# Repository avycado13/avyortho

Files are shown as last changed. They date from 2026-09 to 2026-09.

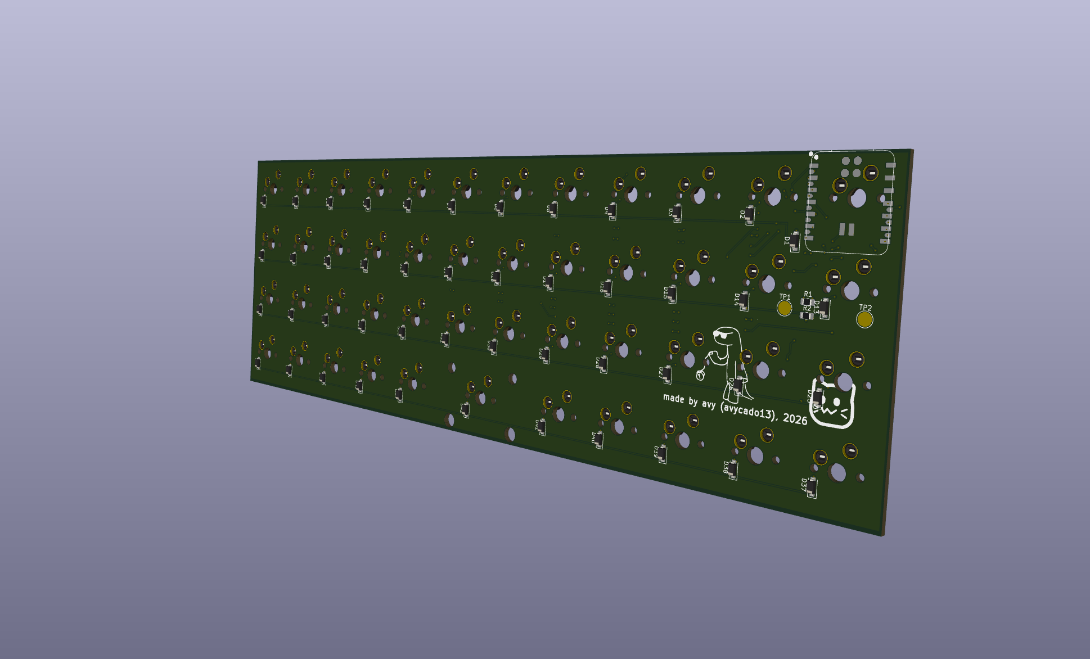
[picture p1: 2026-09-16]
images/avyortho-3b.png

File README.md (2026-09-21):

# AvyOrtho
A basic 40% ortholinear keyboard that uses vim keys for arrows

PCB

I wanted to make a nice keyboard and I wanted one that could be small and easy to carry in my backpack. I decided on an ortholinear because I figured they would be a lot easier to build and route because the keys aren't spaced weirdly. I decided to use ZMK for my firmware because there are nice tools to let you export your JSON from keyboard layout editor and turn it into firmware for ZMK. I used a Seeed Studios XIAO nRF52840 Plus for the microcontroller because it had enough GPIO pins and because it could do batteries without external devices needed

 I chose to go with a minimal 4x12 setup so I could fit it in my bag and to make it cooler. I will probably do keys like function keys with a layer and a modifier key for other functionality. In my next keyboard, I might consider adding RGB lights with something like a sk6812-mini. I will probably mainly use this keyboard on the go and then build a bigger keyboard as my home keyboard.

## Bill of Materials

Components on the PCB (full BOM in [`production/bom.csv`](production/bom.csv)):

| Part | Designators | Qty | Value / Part # | Footprint | Source |
|---|---|-----|---|---|---|
| Diodes | D1-D48 | 47 | 1N4148W (SMD) | D_SOD-123 | [LCSC C241939](https://lcsc.com/product-detail/C241939.html) |
| Resistor | R1 | 1 | 806kΩ | 0805 | CRCW0805806KFKEA |
| Resistor | R2 | 1 | 2MΩ | 0805 | CRCW08052M00FKED |
| MX hotswap sockets | SW1-SW48 | 47 | CPG151101S11-16 (Kailh) | SW_MX_HS | [Adafruit 4958](https://www.adafruit.com/product/4958) |
| MCU | U3 | 1 | Seeed XIAO nRF52840 Plus | XIAO-nRF52840-Plus | [Mouser 713-102010672](https://www.mouser.com/ProductDetail/713-102010672) |

Also these parts for the actual build
- 47x MX switches (any 1u, hot swappable)
- 47x keycaps (1u)
- Case + plate (see [`cad/`](cad/))

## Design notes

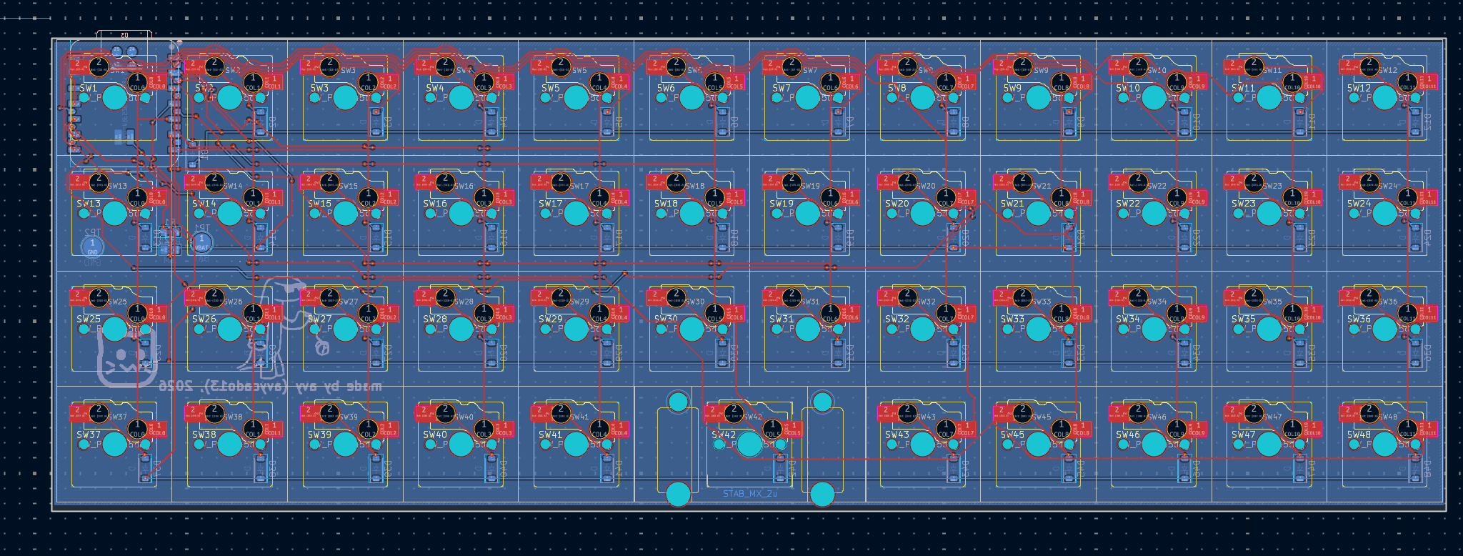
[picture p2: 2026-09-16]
images/avyortho-3a.png

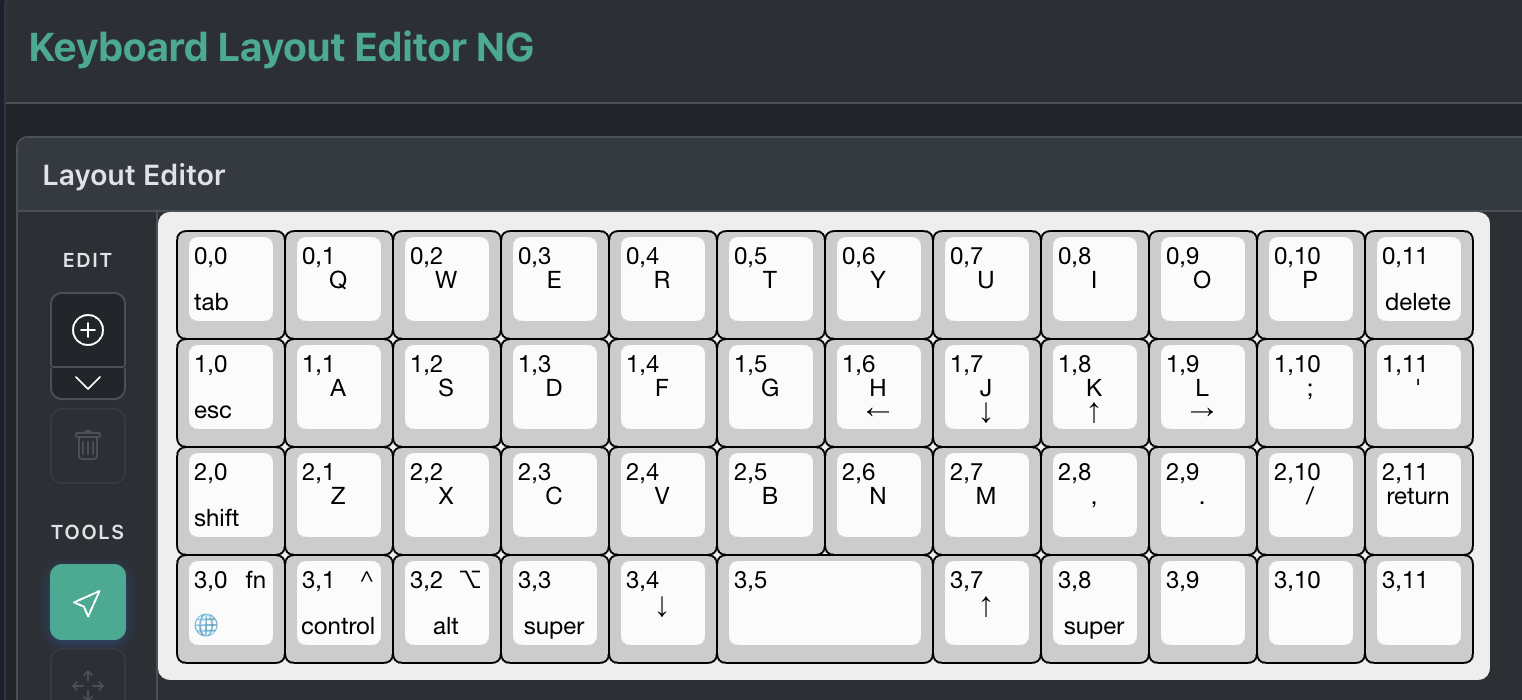
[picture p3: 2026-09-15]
images/avyortho-1a.png

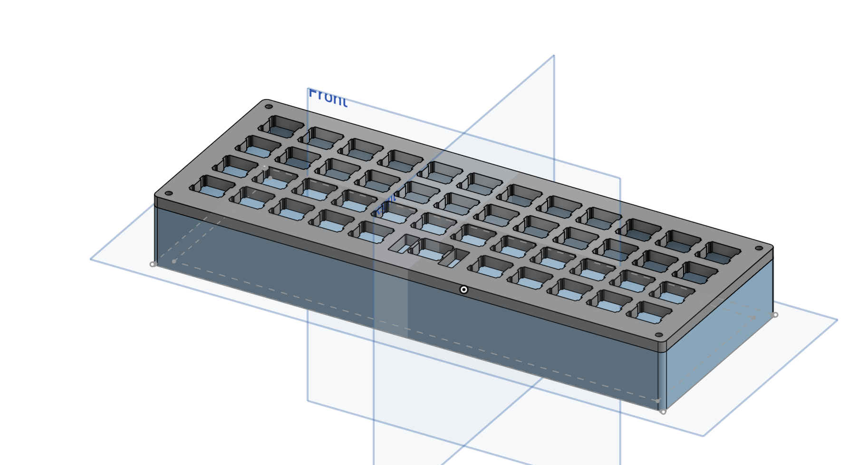
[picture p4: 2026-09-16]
images/avyortho-4.png

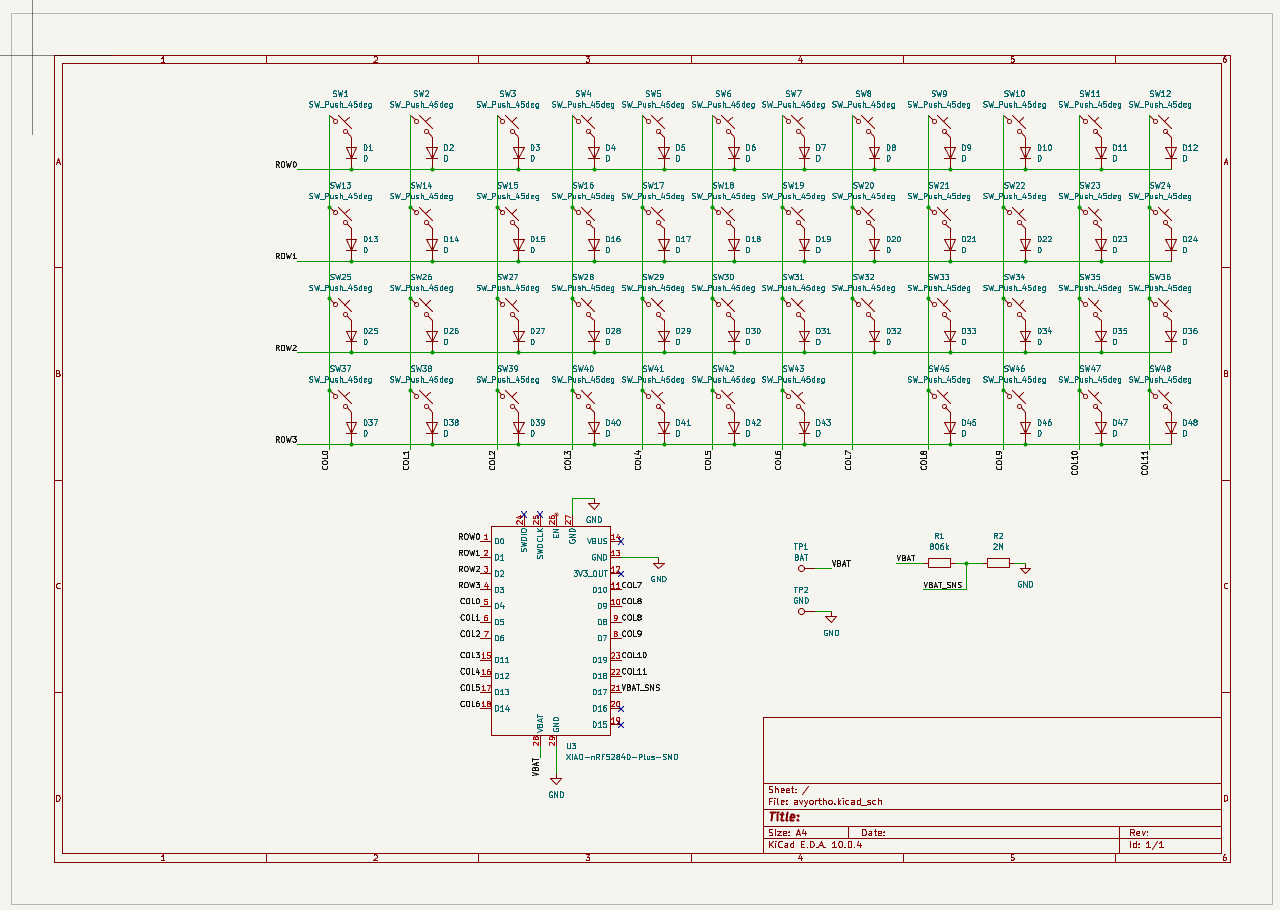
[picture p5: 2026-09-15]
images/avyortho-1b.png

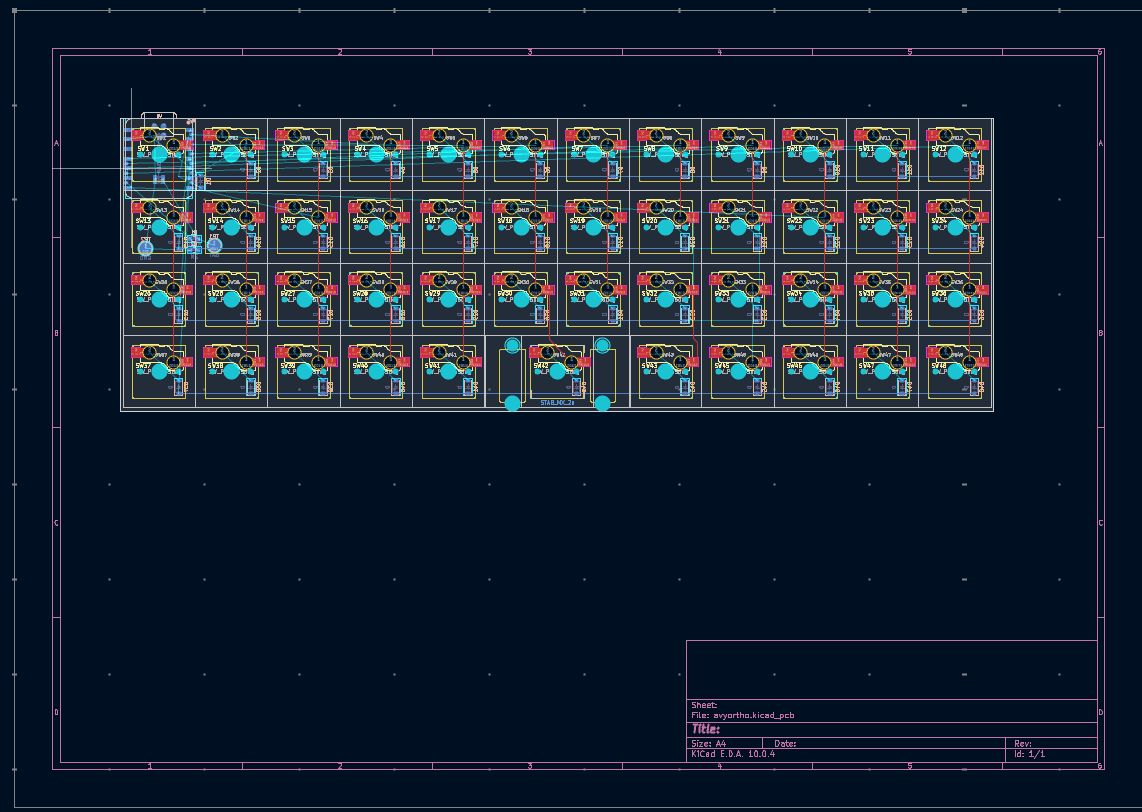
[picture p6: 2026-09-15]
images/avyortho-2.png

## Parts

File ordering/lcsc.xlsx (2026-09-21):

Designator | Footprint | Quantity | Value | LCSC Part # | Original Part | Original Manufacturer | Matched Part Number | Part Match | Description | Quantity | Selected Offers | Selected Distributor | Selected Distributor SKU | Selected Offers (Distributor Link) | Stock | Unit Price, $ | Total Quantity | Total Price
D1, D2, D3, D4, D5, D6, D7, D8, D9, D10, D11, D12, D13, D14, D15, D16, D17, D18, D19, D20, D21, D22, D23, D24, D25, D26, D27, D28, D29, D30, D31, D32, D33, D34, D35, D36, D37, D38, D39, D40, D41, D42, D43, D45, D46, D47, D48 | D_SOD-123 | 47 | D | 1N4148W | 1N4148W |  | 1N4148W-E3-08 | Selected | Rectifier Diode, 1 Phase, 1 Element, 0.15A, 100V V(RRM), Silicon, DO-35 | 47 | LCSC C241939 (https://octopart.com/opatz8j6/a1) | LCSC | C241939 (https://octopart.com/opatz8j6/a1) | https://octopart.com/opatz8j6/a1 | 41470 | 0.037 | 50 | 1.85

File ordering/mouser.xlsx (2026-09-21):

Designator | Footprint | Quantity | Value | LCSC Part # | Original Part | Original Manufacturer | Matched Part Number | Part Match | Description | Quantity | Selected Offers | Selected Distributor | Selected Distributor SKU | Selected Offers (Distributor Link) | Stock | Unit Price, $ | Total Quantity | Total Price
R1 | 0805 | 1 | 806k | CRCW0805806KFKEA | CRCW0805806KFKEA |  | CRCW0805806KFKEA | Exact | Res Thick Film 0805 806K Ohm 1% 0.125W(1/8W) ±100ppm/C Pad SMD T/R Automotive AEC-Q200 | 1 | Mouser 71-CRCW0805-806K-E3 (https://octopart.com/opatz8j6/a1) | Mouser | 71-CRCW0805-806K-E3 (https://octopart.com/opatz8j6/a1) | https://octopart.com/opatz8j6/a1 | 23708 | 0.1 | 1 | 0.1
R2 | 0805 | 1 | 2M | CRCW08052M00FKED | CRCW08052M00FKED |  | CPF0805B2M0E | Selected | Fixed Resistor, Thin Film, 0.1W, 2000000ohm, 0.1% +/-Tol, 25ppm/Cel, Surface Mount, 0805 | 1 | Mouser 279-CPF0805B2M0E (https://octopart.com/opatz8j6/a1) | Mouser | 279-CPF0805B2M0E (https://octopart.com/opatz8j6/a1) | https://octopart.com/opatz8j6/a1 | 9866 | 0.25 | 1 | 0.25
SW1, SW2, SW3, SW4, SW5, SW6, SW7, SW8, SW9, SW10, SW11, SW12, SW13, SW14, SW15, SW16, SW17, SW18, SW19, SW20, SW21, SW22, SW23, SW24, SW25, SW26, SW27, SW28, SW29, SW30, SW31, SW32, SW33, SW34, SW35, SW36, SW37, SW38, SW39, SW40, SW41, SW42, SW43, SW45, SW46, SW47, SW48 | SW_MX_HS_CPG151101S11_1u | 3 | SW_Push_45deg | CPG151101S11-16 | CPG151101S11-16 |  | 4958 | Selected | Kailh Switch Sockets For Mx-Compatible Mechanical Keys - 20 Pack |Adafruit 4958 | 3 | Mouser 485-4958 (https://octopart.com/opatz8j6/a1) | Mouser | 485-4958 (https://octopart.com/opatz8j6/a1) | https://octopart.com/opatz8j6/a1 | 48 | 4.95 | 3 | 14.85
U3 | XIAO-nRF52840-Plus-SMD | 1 | XIAO-nRF52840-Plus-SMD | 102010672 | 102010672 |  | 102010672 | Exact | Xiao NRF52840 Plus | 1 | Mouser 713-102010672 (https://octopart.com/opatz8j6/a1) | Mouser | 713-102010672 (https://octopart.com/opatz8j6/a1) | https://octopart.com/opatz8j6/a1 | 176 | 10.4 | 1 | 10.4

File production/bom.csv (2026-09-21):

Designator | Footprint | Quantity | Value | LCSC Part #
D1, D10, D11, D12, D13, D14, D15, D16, D17, D18, D19, D2, D20, D21, D22, D23, D24, D25, D26, D27, D28, D29, D3, D30, D31, D32, D33, D34, D35, D36, D37, D38, D39, D4, D40, D41, D42, D43, D45, D46, D47, D48, D5, D6, D7, D8, D9 | D_SOD-123 | 47 | D | 1N4148W
R1 | 0805 | 1 | 806k | CRCW0805806KFKEA
R2 | 0805 | 1 | 2M | CRCW08052M00FKED
SW1, SW10, SW11, SW12, SW13, SW14, SW15, SW16, SW17, SW18, SW19, SW2, SW20, SW21, SW22, SW23, SW24, SW25, SW26, SW27, SW28, SW29, SW3, SW30, SW31, SW32, SW33, SW34, SW35, SW36, SW37, SW38, SW39, SW4, SW40, SW41, SW42, SW43, SW45, SW46, SW47, SW48, SW5, SW6, SW7, SW8, SW9 | SW_MX_HS_CPG151101S11_1u | 47 | SW_Push_45deg | CPG151101S11-16
U3 | XIAO-nRF52840-Plus-SMD | 1 | XIAO-nRF52840-Plus-SMD | 102010672

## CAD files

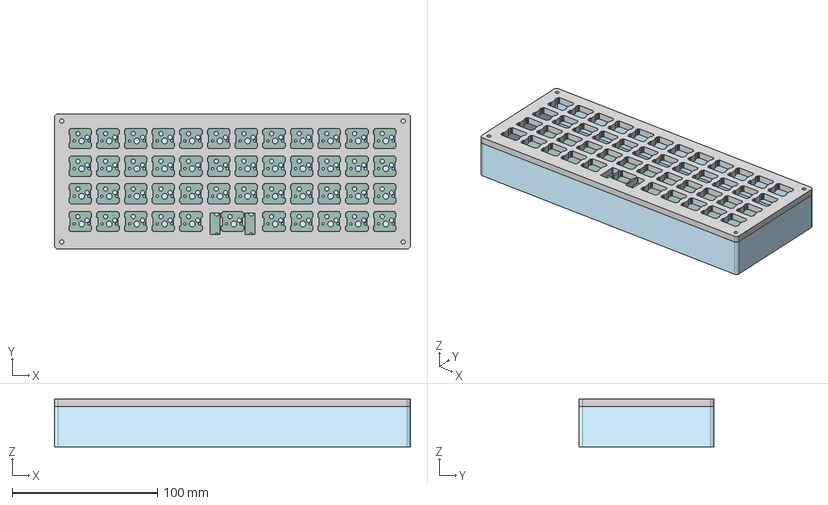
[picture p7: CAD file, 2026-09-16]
cad/full-assembly.step
245.2 x 93.1 x 33.0 mm
avyortho_PCB

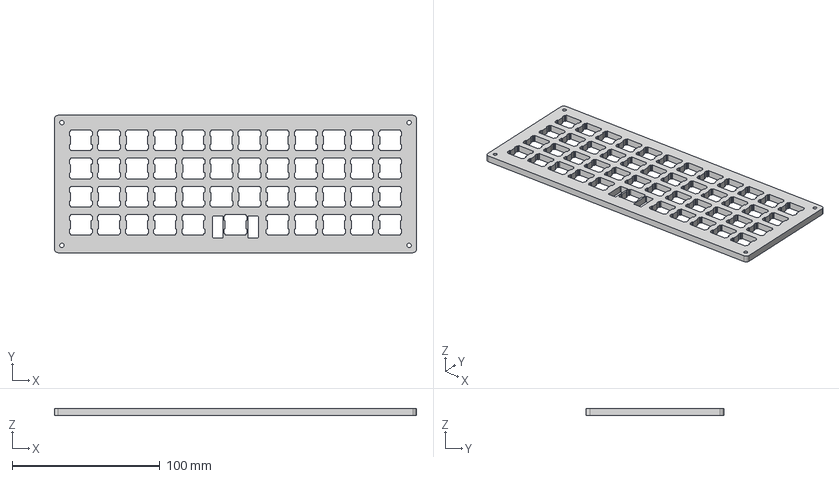
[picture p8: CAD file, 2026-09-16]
cad/plate.step
245.2 x 93.1 x 5.00 mm

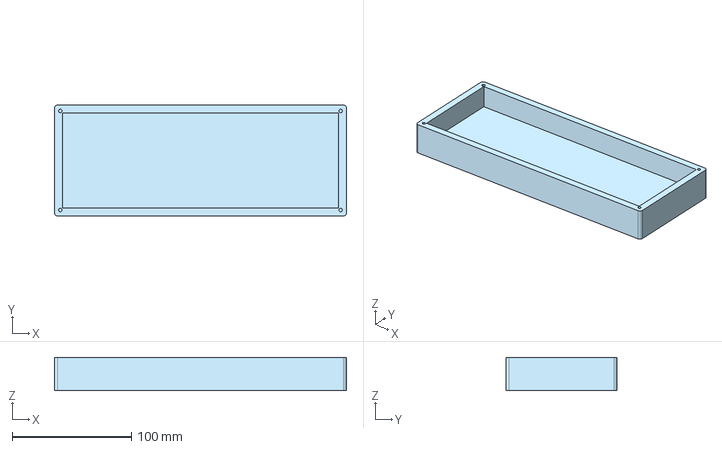
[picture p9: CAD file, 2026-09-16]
cad/body.step
245.2 x 93.1 x 28.0 mm

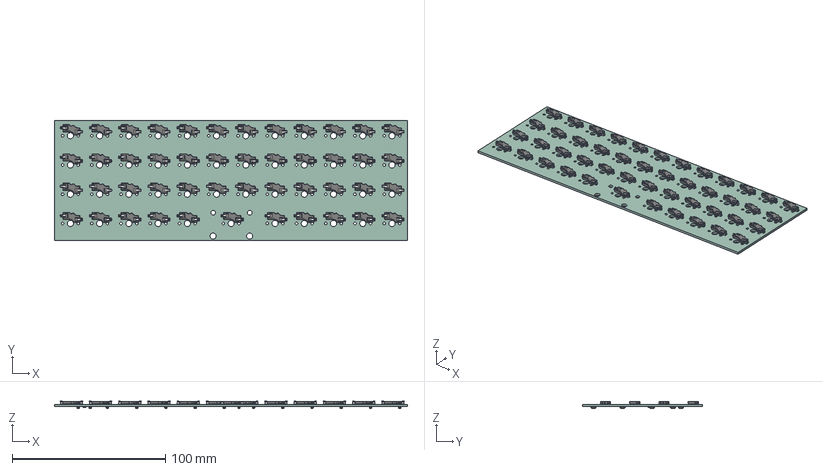
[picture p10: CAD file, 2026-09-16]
cad/pcb.step
230.0 x 78.0 x 4.74 mm
HS_gat_mx v8 x 47
D_SOD-123 x 47
R_0805_2012Metric x 2
avyortho_PCB

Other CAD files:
cad/body.3mf

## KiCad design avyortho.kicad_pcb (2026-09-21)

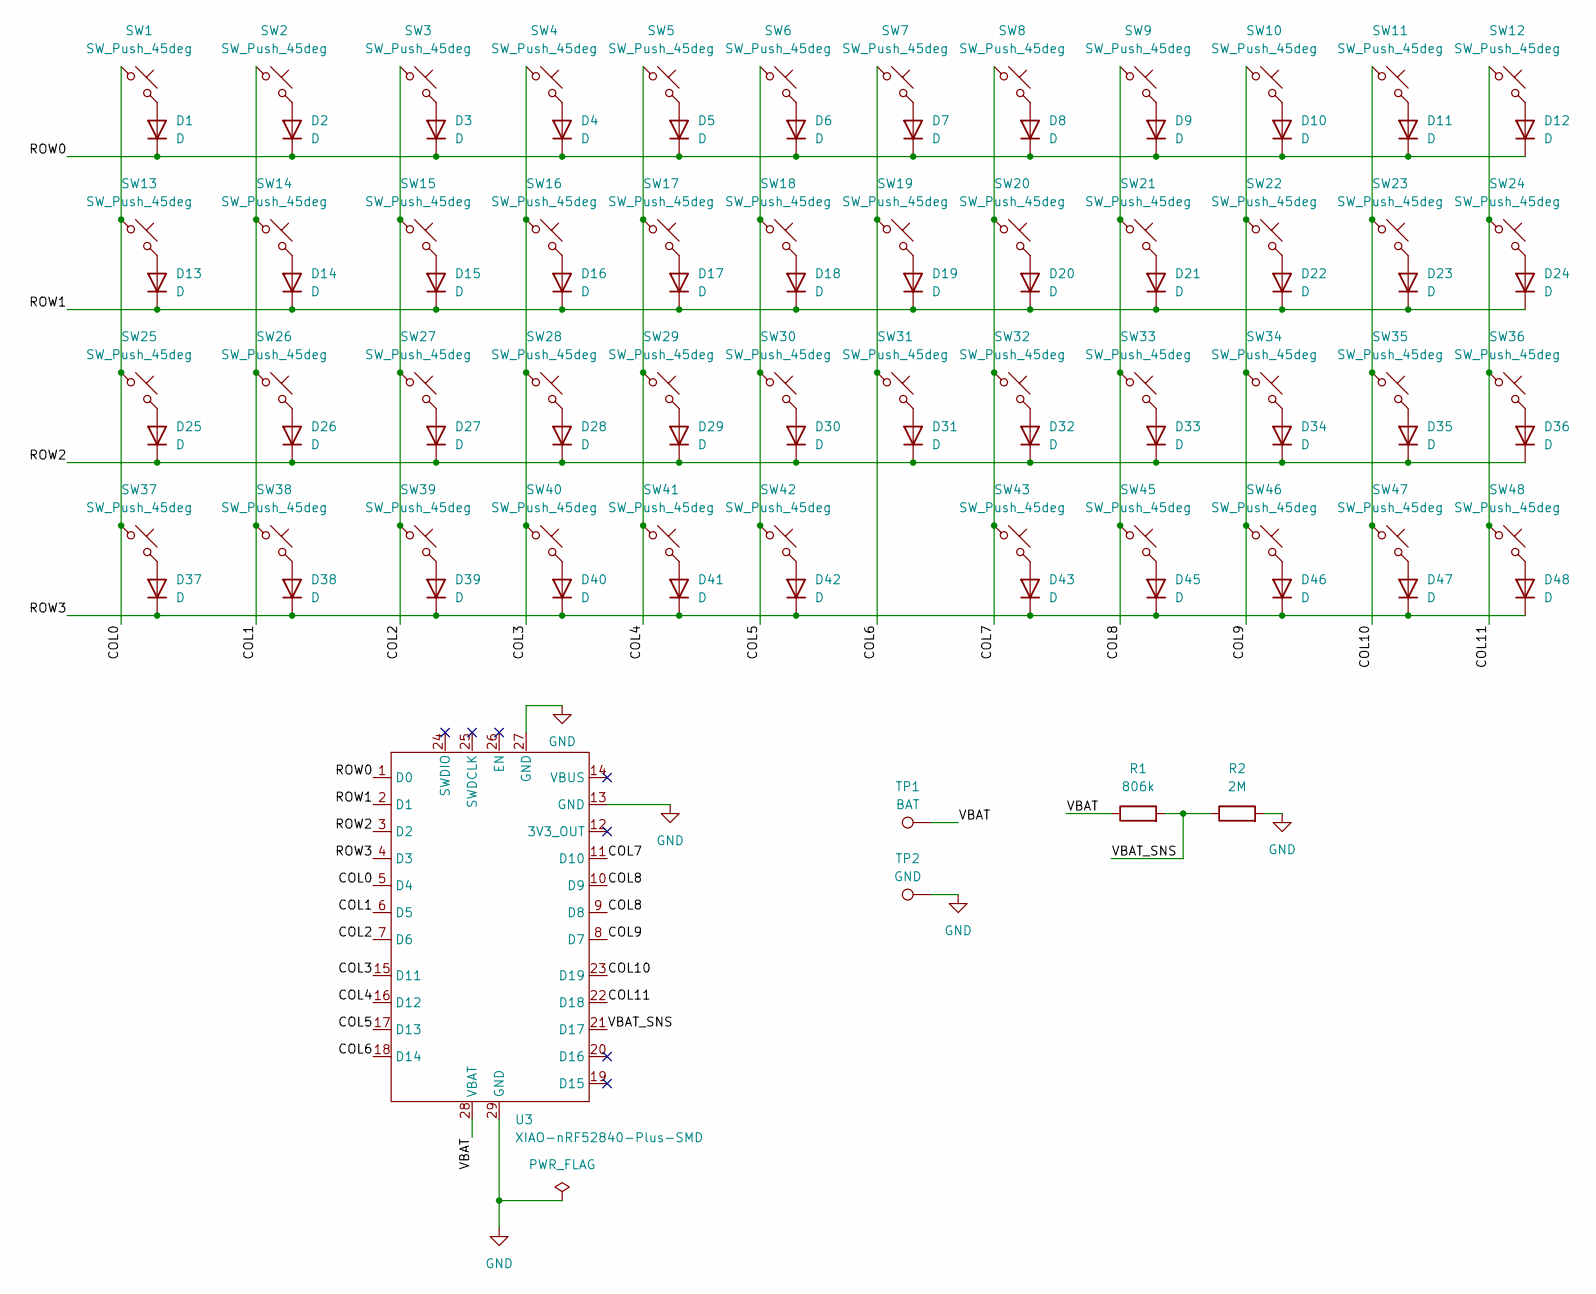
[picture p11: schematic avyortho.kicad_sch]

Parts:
D1, D2, D3, D4, D5, D6, D7, D8, D9, D10, D11, D12, D13, D14, D15, D16, D17, D18, D19, D20, D21, D22, D23, D24, D25, D26, D27, D28, D29, D30, D31, D32, D33, D34, D35, D36, D37, D38, D39, D40, D41, D42, D43, D45, D46, D47, D48: D; D_SOD-123; MPN 1N4148W
R1: 806k; R_0805_2012Metric_Pad1.20x1.40mm_HandSolder; MPN CRCW0805806KFKEA
R2: 2M; R_0805_2012Metric_Pad1.20x1.40mm_HandSolder; MPN CRCW08052M00FKED
SW1, SW2, SW3, SW4, SW5, SW6, SW7, SW8, SW9, SW10, SW11, SW12, SW13, SW14, SW15, SW16, SW17, SW18, SW19, SW20, SW21, SW22, SW23, SW24, SW25, SW26, SW27, SW28, SW29, SW30, SW31, SW32, SW33, SW34, SW35, SW36, SW37, SW38, SW39, SW40, SW41, SW42, SW43, SW45, SW46, SW47, SW48: SW_Push_45deg; SW_MX_HS_CPG151101S11_1u; MPN CPG151101S11-16
TP1: BAT; TestPoint_Pad_D3.0mm
TP2: GND; TestPoint_Pad_D3.0mm
U3: XIAO-nRF52840-Plus-SMD; MPN 102010672

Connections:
/COL0: SW1.1, SW13.1, SW25.1, SW37.1, U3.5 (D4)
/COL1: SW2.1, SW14.1, SW26.1, SW38.1, U3.6 (D5)
/COL2: SW3.1, SW15.1, SW27.1, SW39.1, U3.7 (D6)
/COL3: SW4.1, SW16.1, SW28.1, SW40.1, U3.15 (D11)
/COL4: SW5.1, SW17.1, SW29.1, SW41.1, U3.16 (D12)
/COL5: SW6.1, SW18.1, SW30.1, SW42.1, U3.17 (D13)
/COL6: SW7.1, SW19.1, SW31.1, U3.18 (D14)
/COL7: SW8.1, SW20.1, SW32.1, SW43.1, U3.11 (D10)
/COL8: SW9.1, SW21.1, SW33.1, SW45.1, U3.9 (D8), U3.10 (D9)
/COL9: SW10.1, SW22.1, SW34.1, SW46.1, U3.8 (D7)
/COL10: SW11.1, SW23.1, SW35.1, SW47.1, U3.23 (D19)
/COL11: SW12.1, SW24.1, SW36.1, SW48.1, U3.22 (D18)
/ROW0: D1.1 (K), D2.1 (K), D3.1 (K), D4.1 (K), D5.1 (K), D6.1 (K), D7.1 (K), D8.1 (K), D9.1 (K), D10.1 (K), D11.1 (K), D12.1 (K), U3.1 (D0)
/ROW1: D13.1 (K), D14.1 (K), D15.1 (K), D16.1 (K), D17.1 (K), D18.1 (K), D19.1 (K), D20.1 (K), D21.1 (K), D22.1 (K), D23.1 (K), D24.1 (K), U3.2 (D1)
/ROW2: D25.1 (K), D26.1 (K), D27.1 (K), D28.1 (K), D29.1 (K), D30.1 (K), D31.1 (K), D32.1 (K), D33.1 (K), D34.1 (K), D35.1 (K), D36.1 (K), U3.3 (D2)
/ROW3: D37.1 (K), D38.1 (K), D39.1 (K), D40.1 (K), D41.1 (K), D42.1 (K), D43.1 (K), D45.1 (K), D46.1 (K), D47.1 (K), D48.1 (K), U3.4 (D3)
/VBAT: R1.1, TP1.1 (1_1), U3.28 (VBAT)
/VBAT_SNS: R1.2, R2.1, U3.21 (D17)
GND: R2.2, TP2.1 (1_1), U3.13 (GND), U3.27 (GND), U3.29 (GND)
unnamed: D1.2 (A), SW1.2
unnamed: D2.2 (A), SW2.2
unnamed: D3.2 (A), SW3.2
unnamed: D4.2 (A), SW4.2
unnamed: D5.2 (A), SW5.2
unnamed: D6.2 (A), SW6.2
unnamed: D7.2 (A), SW7.2
unnamed: D8.2 (A), SW8.2
unnamed: D9.2 (A), SW9.2
unnamed: D10.2 (A), SW10.2
unnamed: D11.2 (A), SW11.2
unnamed: D12.2 (A), SW12.2
unnamed: D13.2 (A), SW13.2
unnamed: D14.2 (A), SW14.2
unnamed: D15.2 (A), SW15.2
unnamed: D16.2 (A), SW16.2
unnamed: D17.2 (A), SW17.2
unnamed: D18.2 (A), SW18.2
unnamed: D19.2 (A), SW19.2
unnamed: D20.2 (A), SW20.2
unnamed: D21.2 (A), SW21.2
unnamed: D22.2 (A), SW22.2
unnamed: D23.2 (A), SW23.2
unnamed: D24.2 (A), SW24.2
unnamed: D25.2 (A), SW25.2
unnamed: D26.2 (A), SW26.2
unnamed: D27.2 (A), SW27.2
unnamed: D28.2 (A), SW28.2
unnamed: D29.2 (A), SW29.2
unnamed: D30.2 (A), SW30.2
unnamed: D31.2 (A), SW31.2
unnamed: D32.2 (A), SW32.2
unnamed: D33.2 (A), SW33.2
unnamed: D34.2 (A), SW34.2
unnamed: D35.2 (A), SW35.2
unnamed: D36.2 (A), SW36.2
unnamed: D37.2 (A), SW37.2
unnamed: D38.2 (A), SW38.2
unnamed: D39.2 (A), SW39.2
unnamed: D40.2 (A), SW40.2
unnamed: D41.2 (A), SW41.2
unnamed: D42.2 (A), SW42.2
unnamed: D43.2 (A), SW43.2
unnamed: D45.2 (A), SW45.2
unnamed: D46.2 (A), SW46.2
unnamed: D47.2 (A), SW47.2
unnamed: D48.2 (A), SW48.2

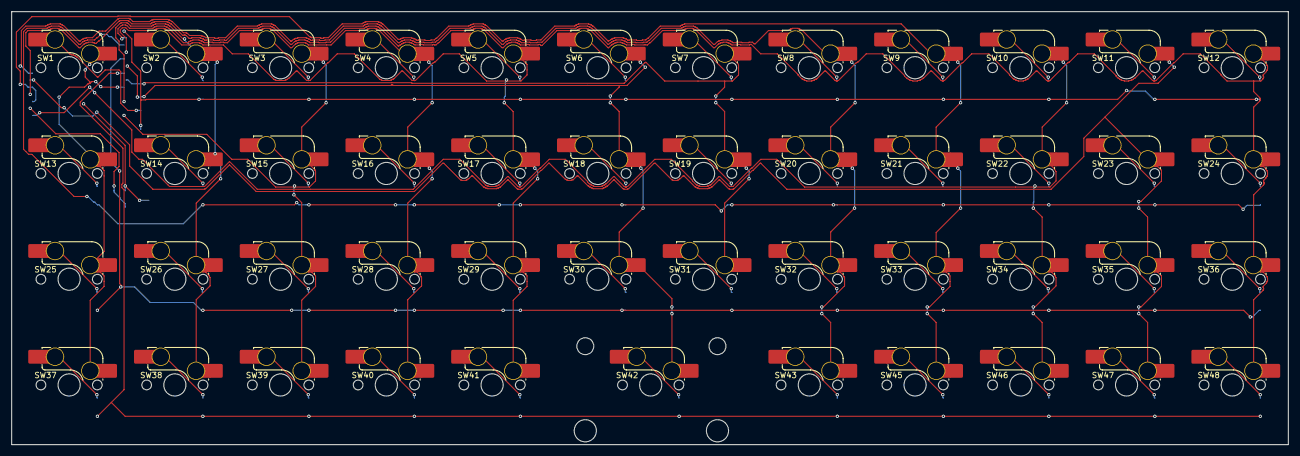
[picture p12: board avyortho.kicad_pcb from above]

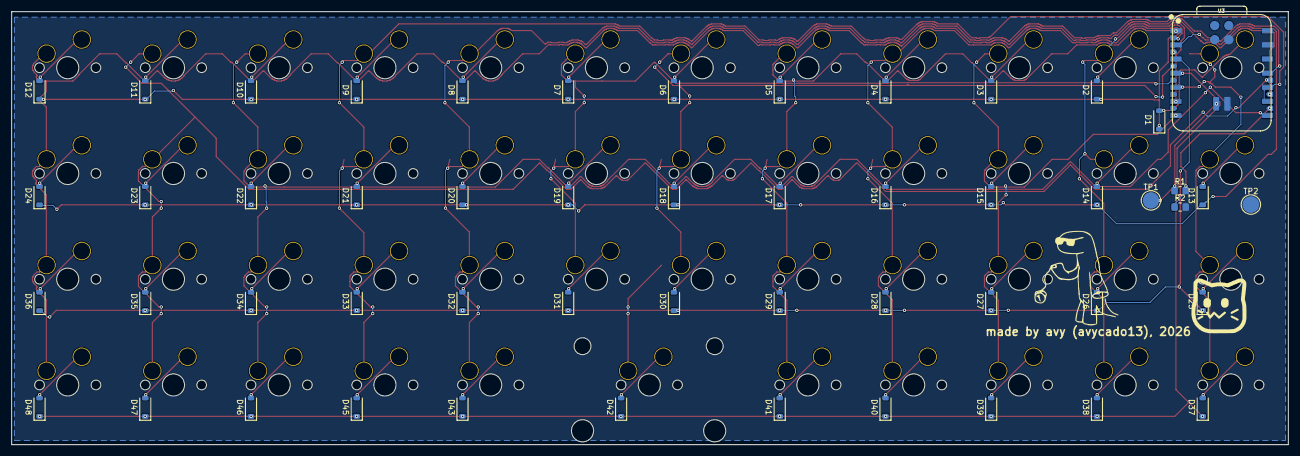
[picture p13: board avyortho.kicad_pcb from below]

Board: 2 copper layers, 230.0 x 78.0 mm, 99 parts (52 on the bottom side), 66 nets.

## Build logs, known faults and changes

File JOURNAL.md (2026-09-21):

---
title: "AvyOrtho"
github: "avycado13/avyortho"
description: "A basic 40% ortholinear keyboard that uses vim keys for arrow"
created_at: "2026-09-14"
---

# September 14: Make Schematic and Design
I have had the idea of a 40% ortho floating around in my head for a few days now and with half life prep week one starting today, I thought this would be perfect. I made a design for it in [Keyboard Layout Editor NG](https://editor.keyboard-tools.xyz/)
and then made a quick schematic in KiCad. I used the [Stasis split keyboard guide](https://stasis.hackclub.com/starter-projects/split-keyboard) as a reference for parts of it.

KLE Layout
KiCad schematic
**Total time spent: 2h**

# September 15: Laid out PCB and Assigned Footprints
I assigned footprints and decided to go with hot swappable MX switches using Gateron KS-2P02B01-01 hot swap sockets. I also laid out my design using an extension to parse my keyboard layout editor JSON.

KiCad PCB

**Total time spent: 1h**

# September 15: Routed PCB + Added Silkscreen
I routed the PCB and added some really cool silkscreen art to it to make it look cool! I added an Orpheus using a yoyo from [dinosaurs](https://rawr.hackclub.com/) (thanks Arslaan!) and a Neocat.

**Total time spent: 1h**
Routed PCB
3D View of PCB with silkscreen

# September 16: CADed Case
I made a case that is about 240 mm long and added a plate. onshape kinda sucks because of constraints, but I guess I made it work.

**Total time spent: 1h**
CAD of case

# September 20: Add BOMs and Do README
I made the BOM in Octopart and wrote the README. I uploaded the gerbers to JLC and all together the the price of it was 45 bucks excluding switches.

Octopart

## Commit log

2026-09-15 layout pcb
    [avyortho.kicad_pcb, avyortho.kicad_sch]
2026-09-16 route pcb and add silkscreen
    [avyortho.kicad_pcb]
2026-09-16 CAD case
    [body.3mf, body.step, full-assembly.step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]
2026-09-17 switch sockets to Kalih CPG151101S11-16 because available at lcsc
    [avyortho.kicad_pcb, avyortho.kicad_sch]
2026-09-17 make fabrication files
    [avyortho.kicad_pcb, bom.csv, designators.csv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]
2026-09-21 changes for submitting to half life prep week one
    [avyortho.kicad_pcb, avyortho.kicad_sch, bom.csv]
2026-09-21 BOM and ordering stuff
    [lcsc.xlsx, mouser.xlsx, octopart.xlsx]
2026-09-21 journal time on bom
2026-10-22 Add prices to BOM
2026-10-22 Add CAD image to bom
